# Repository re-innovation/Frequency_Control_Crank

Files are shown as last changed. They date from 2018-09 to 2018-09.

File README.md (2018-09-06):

# Frequency_Control_Crank

A crank handled swicth that controls power to things when turned.
This was built for an update to the Kinetiscopes from Ben Wigley.
Some ifnormation and video is available here:

https://www.re-innovation.co.uk/portfolio/kinetiscopes-a-lost-paradise/

This repository has the arduino nano control code, the design files for the magnetic sensor and datasheets for the control board used.
It also includes some photos.

To Do:

* Upload photos
* Do dimensioned design for future use

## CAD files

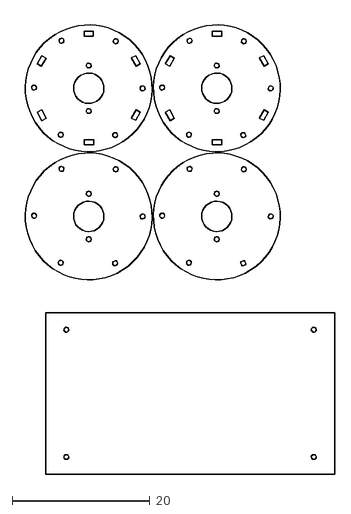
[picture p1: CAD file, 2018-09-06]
Magnet_Holder_Design/magnet holder v1.dxf
46.3 x 66.6

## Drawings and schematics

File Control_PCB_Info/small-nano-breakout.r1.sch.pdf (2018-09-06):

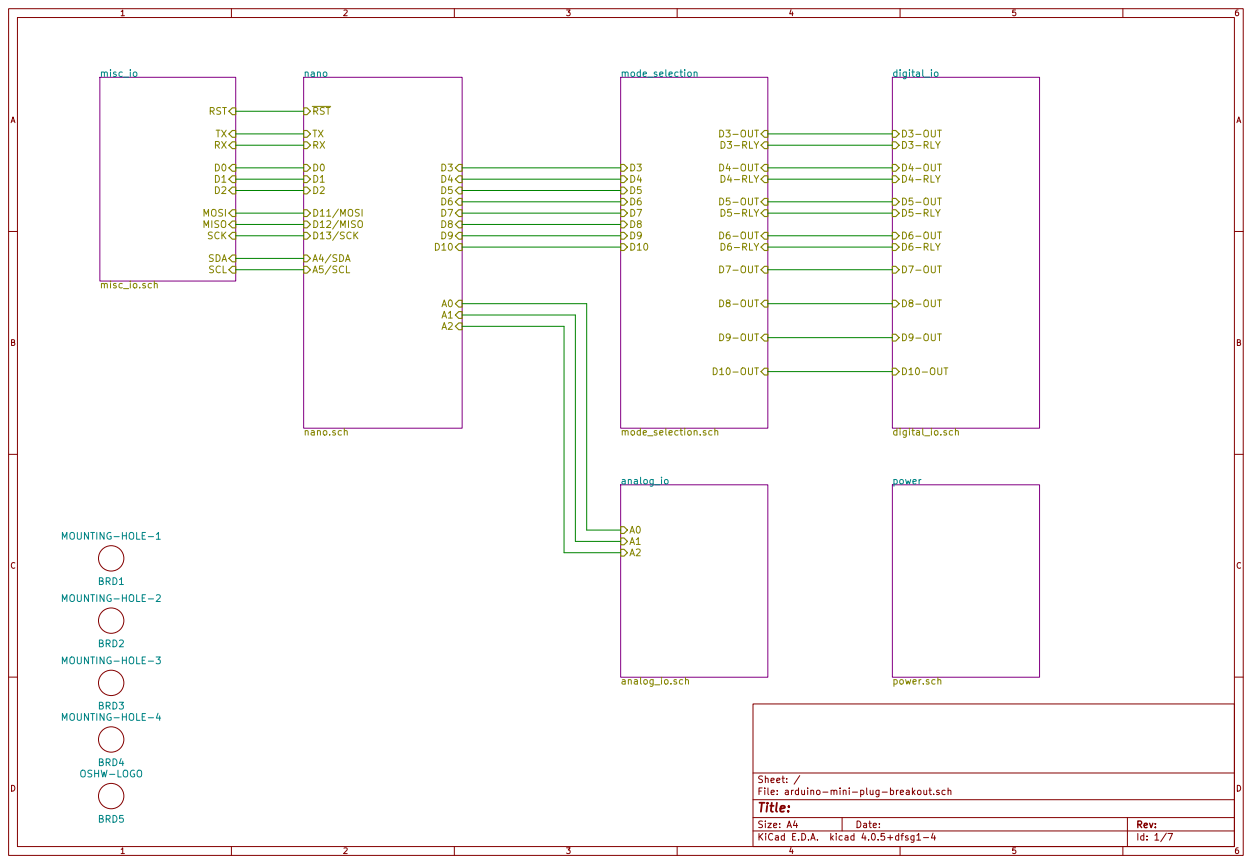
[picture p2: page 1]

D10-OUT D3-RLY D4-RLY D5-RLY D6-RLY mode_selection

BRD4 MOUNTING-HOLE-4 BRD3 MOUNTING-HOLE-3 BRD2 MOUNTING-HOLE-2 BRD1 MOUNTING-HOLE-1

File: arduino-mini-plug-breakout.sch Sheet: /
Id: 1/7 Title:

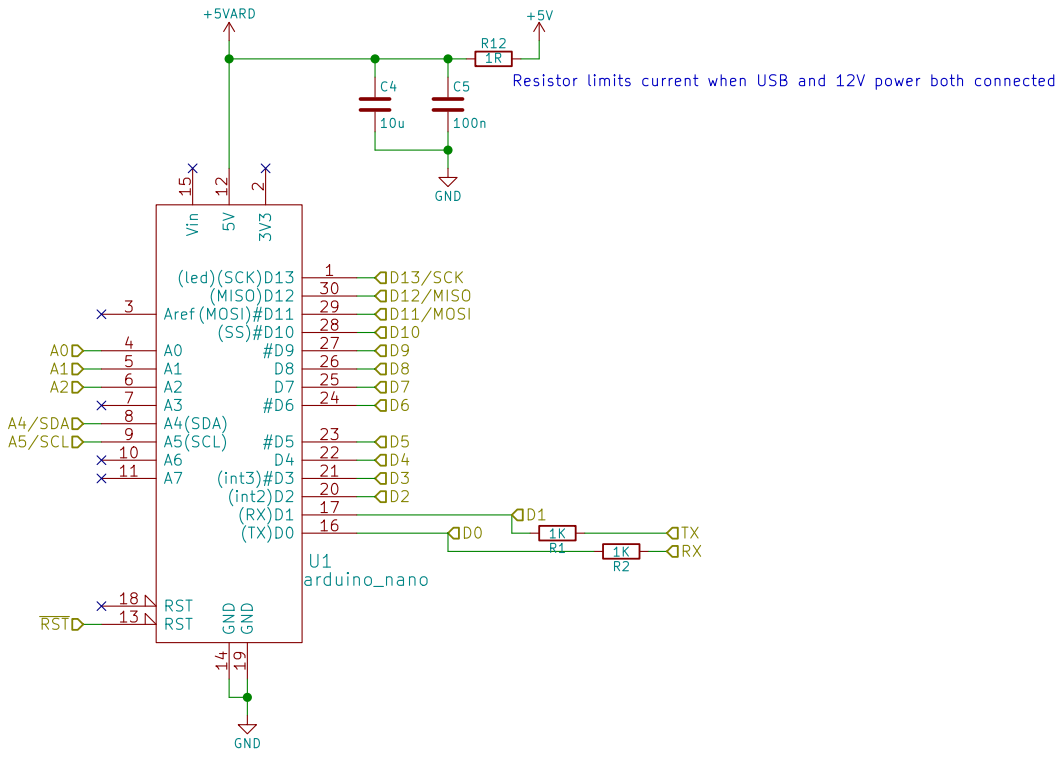
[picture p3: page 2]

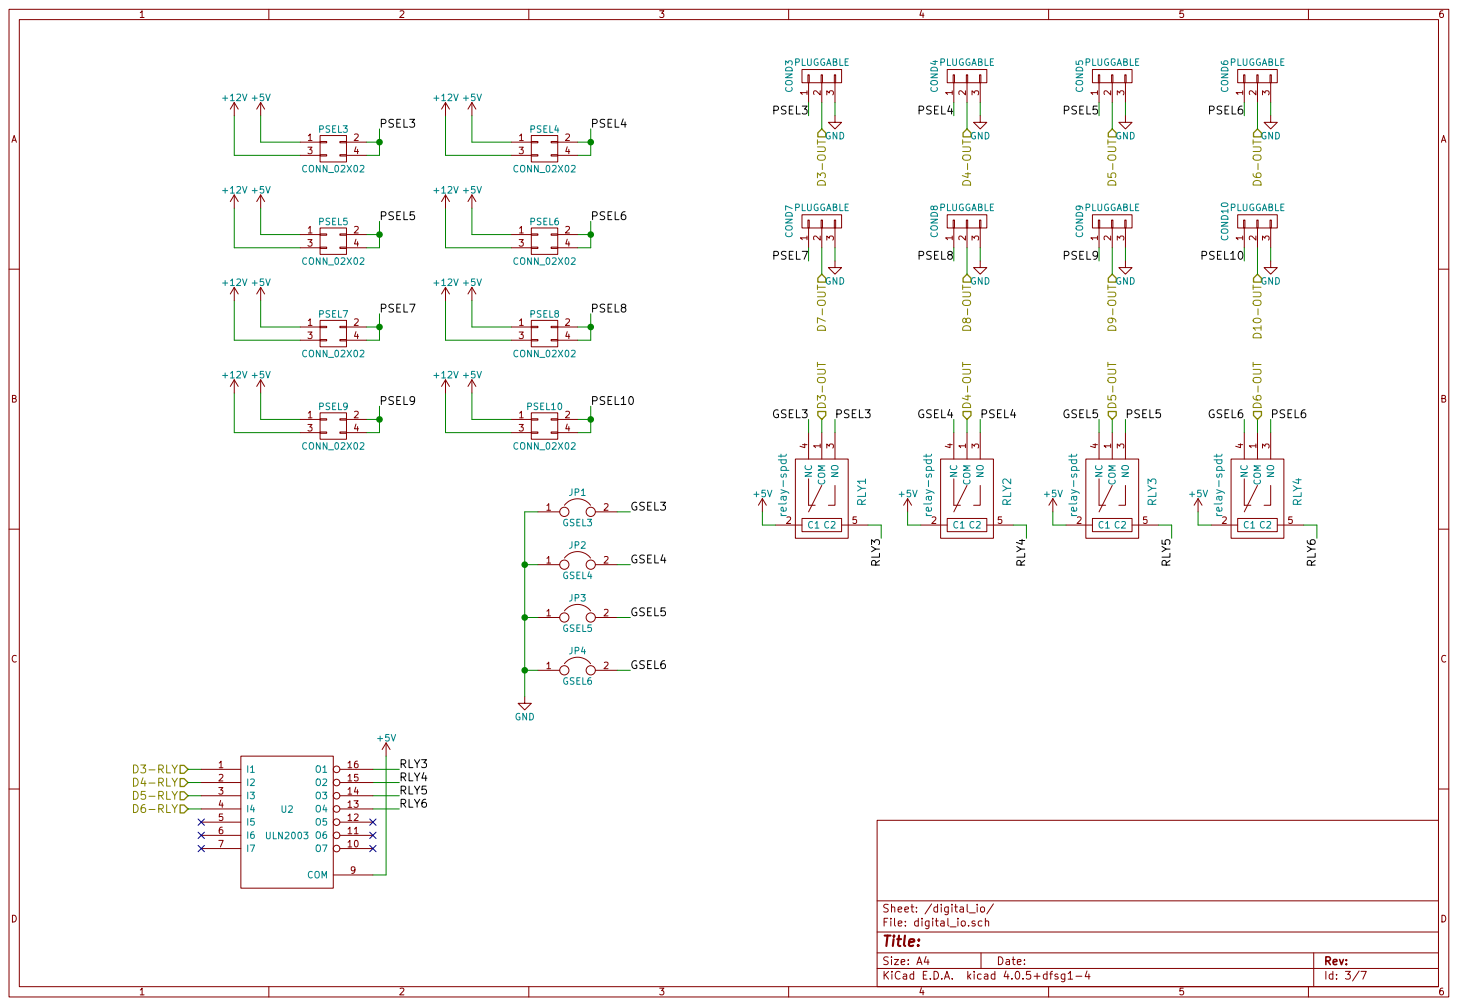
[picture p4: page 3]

3 PLUGGABLE D3-OUT D4-OUT D5-OUT D6-OUT D7-OUT D8-OUT D9-OUT D10-OUT COM

4 C2 5 RLY4 relay-spdt +5V +5V +5V +5V D3-RLY D4-RLY D5-RLY D6-RLY

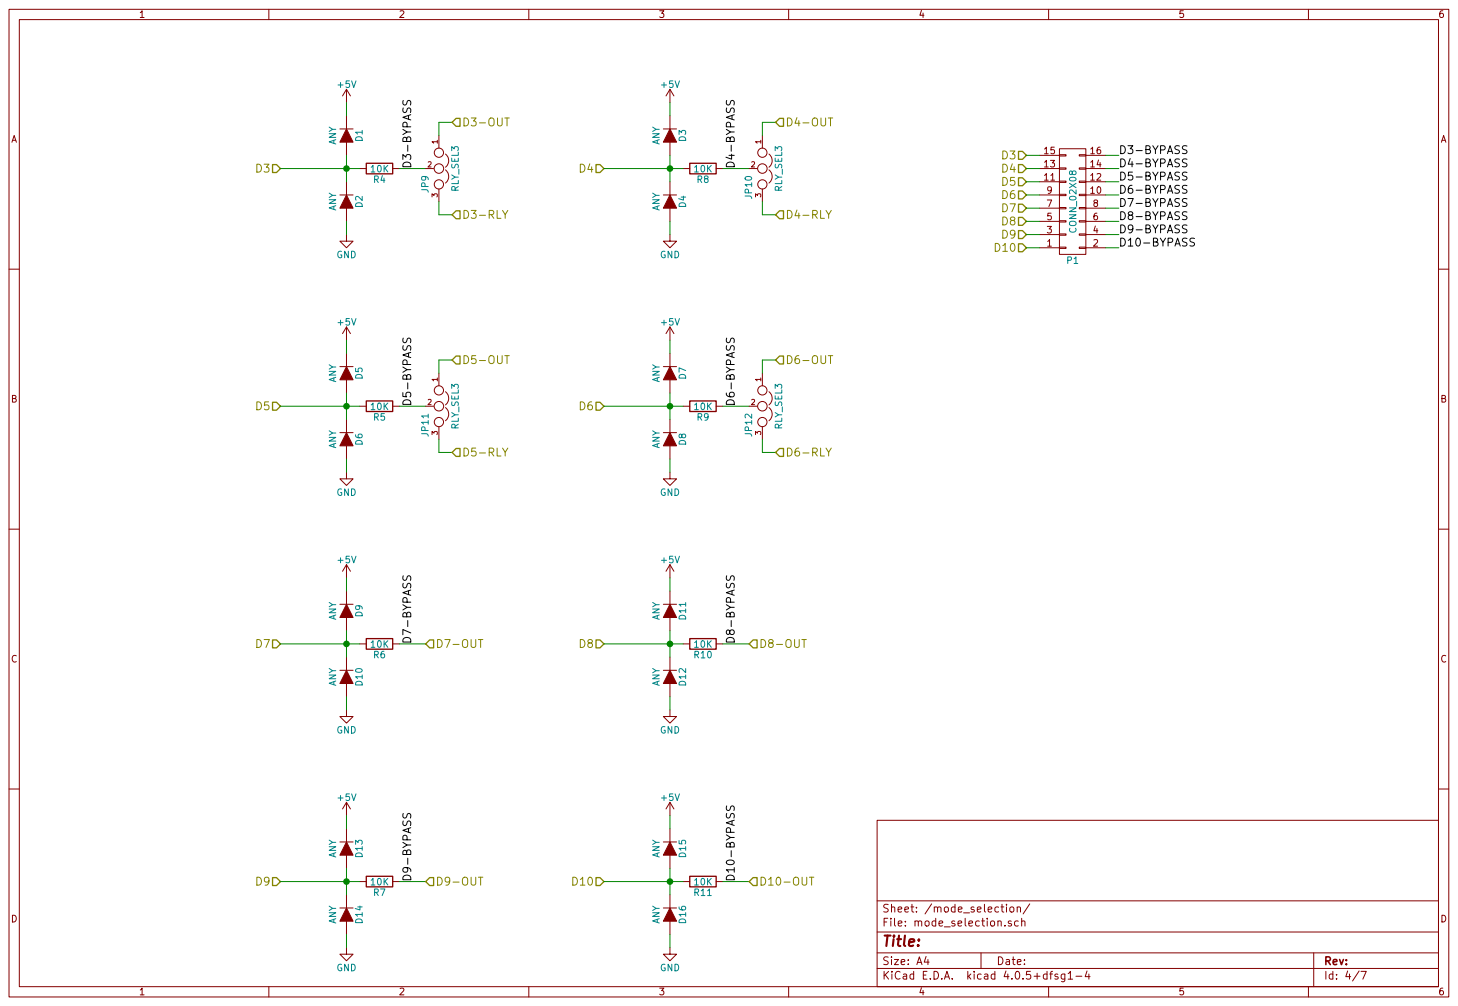
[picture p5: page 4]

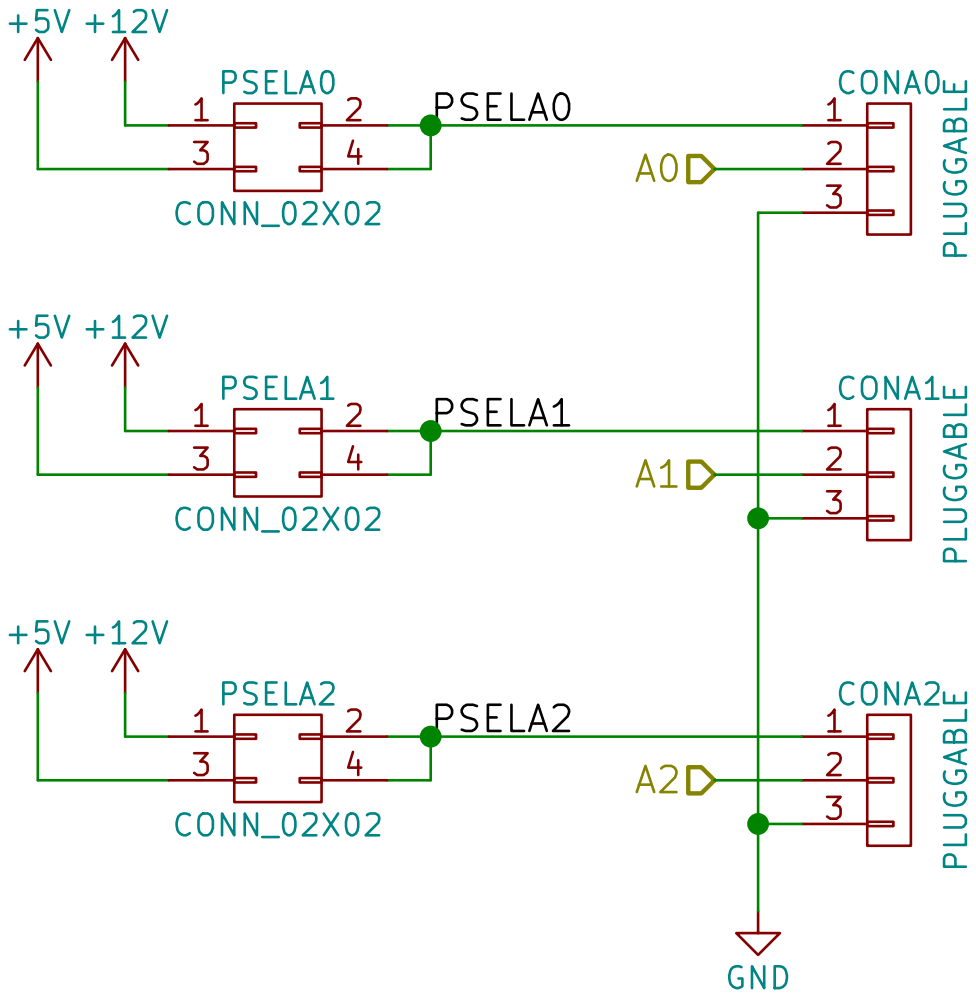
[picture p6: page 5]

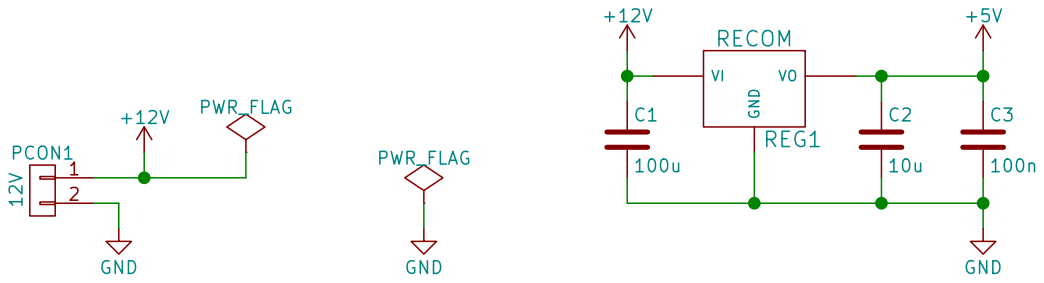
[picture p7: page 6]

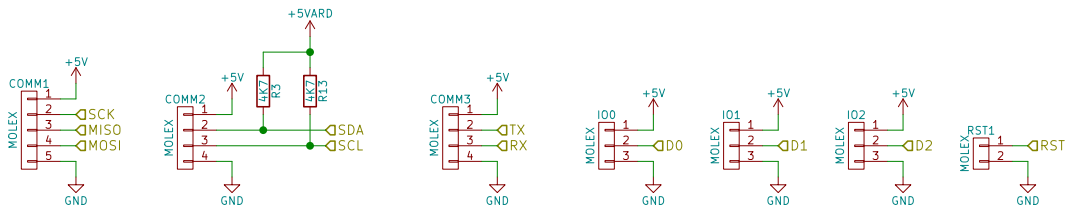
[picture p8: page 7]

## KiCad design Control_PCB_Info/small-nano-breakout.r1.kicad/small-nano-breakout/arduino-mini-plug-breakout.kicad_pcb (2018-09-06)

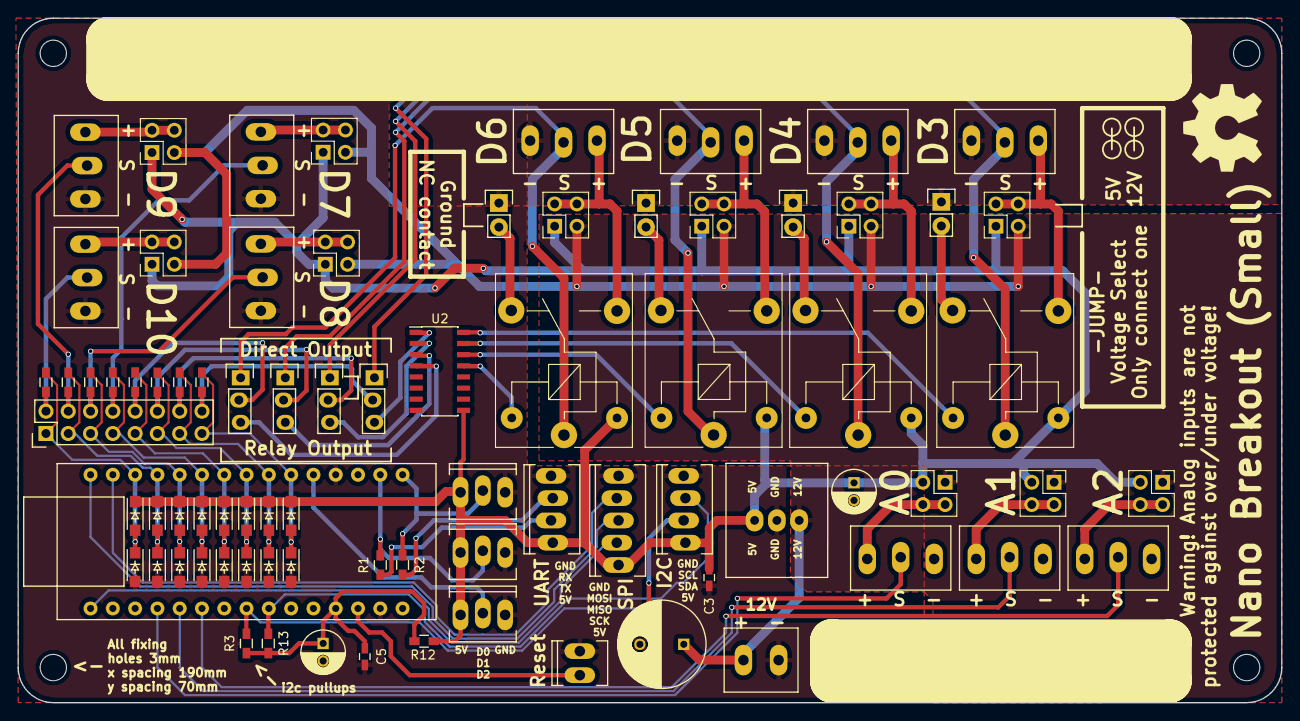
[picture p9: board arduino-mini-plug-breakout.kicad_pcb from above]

Board: 2 copper layers, 144.0 x 78.0 mm, 85 parts (0 on the bottom side), 61 nets.

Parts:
BRD1: MOUNTING-HOLE-1; MountingHole_3mm
BRD2: MOUNTING-HOLE-2; MountingHole_3mm
BRD3: MOUNTING-HOLE-3; MountingHole_3mm
BRD4: MOUNTING-HOLE-4; MountingHole_3mm
BRD5: OSHW-LOGO; OSHW-logo_silkscreen-front_10mm
C1: 100u; C_Radial_D10_L13_P5
C2, C4: 10u; C_Radial_D5_L11_P2
C3, C5: 100n; C_0603_HandSoldering
COMM1: MOLEX; Socket_MOLEX-KK-RM2-54mm_Lock_5pin_straight
COMM2, COMM3: MOLEX; Socket_MOLEX-KK-RM2-54mm_Lock_4pin_straight
CONA0, CONA1, CONA2: PLUGGABLE; Standard_3Way_OffsetHoles
COND3, COND4, COND5, COND6, COND7, COND8, COND9, COND10: PLUGGABLE; Standard_3Way_OffsetHoles
D1, D2, D3, D4, D5, D6, D7, D8, D9, D10, D11, D12, D13, D14, D15, D16: ANY; SOD-123
IO0, IO1, IO2: MOLEX; Socket_MOLEX-KK-RM2-54mm_Lock_3pin_straight
JP1: GSEL3; Pin_Header_Straight_1x02
JP2: GSEL4; Pin_Header_Straight_1x02
JP3: GSEL5; Pin_Header_Straight_1x02
JP4: GSEL6; Pin_Header_Straight_1x02
JP9, JP10, JP11, JP12: RLY_SEL3; Pin_Header_Straight_1x03
P1: CONN_02X08; Pin_Header_Straight_2x08
PCON1: 12V; Standard_2Way_OffsetHoles
PSEL3, PSEL4, PSEL5, PSEL6, PSEL7, PSEL8, PSEL9, PSEL10: CONN_02X02; Pin_Header_Straight_2x02_Pitch2.54mm
PSELA0, PSELA1, PSELA2: CONN_02X02; Pin_Header_Straight_2x02_Pitch2.54mm
R1, R2: 1K; R_0603_HandSoldering
R3, R13: 4K7; R_0603_HandSoldering
R4, R5, R6, R7, R8, R9, R10, R11: 10K; R_0603_HandSoldering
R12: 1R; R_0603_HandSoldering
REG1: RECOM; DCDC-Conv_Recom_R-78HBxx-0.5
RLY1, RLY2, RLY3, RLY4: relay-spdt; Relay_SPDT_SANYOU_SRD_Series_Form_C
RST1: MOLEX; Socket_MOLEX-KK-RM2-54mm_Lock_2pin_straight
U1: arduino_nano; nano
U2: ULN2003; SOIC-16_3.9x9.9mm_Pitch1.27mm

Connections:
+5V: C2.1, C3.1, COMM1.1, COMM2.1, COMM3.1, D1.1, D3.1, D5.1, D7.1, D9.1, D11.1, D13.1, D15.1, IO0.1, IO1.1, IO2.1, PSEL3.1, PSEL4.1, PSEL5.1, PSEL6.1, PSEL7.1, PSEL8.1, PSEL9.1, PSEL10.1, PSELA0.3, PSELA1.3, PSELA2.3, R12.2, REG1.3, RLY1.2, RLY2.2, RLY3.2, RLY4.2, U2.9
+5VARD: C4.1, C5.1, R3.1, R12.1, R13.1, U1.12
+12V: C1.1, PCON1.1, PSEL3.3, PSEL4.3, PSEL5.3, PSEL6.3, PSEL7.3, PSEL8.3, PSEL9.3, PSEL10.3, PSELA0.1, PSELA1.1, PSELA2.1, REG1.1
/analog_io/A0: CONA0.2, U1.4
/analog_io/A1: CONA1.2, U1.5
/analog_io/A2: CONA2.2, U1.6
/analog_io/PSELA0: CONA0.1, PSELA0.2, PSELA0.4
/analog_io/PSELA1: CONA1.1, PSELA1.2, PSELA1.4
/analog_io/PSELA2: CONA2.1, PSELA2.2, PSELA2.4
/digital_io/D3-OUT: COND3.2, JP9.1, RLY1.1
/digital_io/D3-RLY: JP9.3, U2.1
/digital_io/D4-OUT: COND4.2, JP10.1, RLY2.1
/digital_io/D4-RLY: JP10.3, U2.2
/digital_io/D5-OUT: COND5.2, JP11.1, RLY3.1
/digital_io/D5-RLY: JP11.3, U2.3
/digital_io/D6-OUT: COND6.2, JP12.1, RLY4.1
/digital_io/D6-RLY: JP12.3, U2.4
/digital_io/D7-OUT: COND7.2, P1.8, R6.1
/digital_io/D8-OUT: COND8.2, P1.6, R10.1
/digital_io/D9-OUT: COND9.2, P1.4, R7.1
/digital_io/D10-OUT: COND10.2, P1.2, R11.1
/digital_io/GSEL3: JP1.2, RLY1.4
/digital_io/GSEL4: JP2.2, RLY2.4
/digital_io/GSEL5: JP3.2, RLY3.4
/digital_io/GSEL6: JP4.2, RLY4.4
/digital_io/PSEL3: COND3.1, PSEL3.2, PSEL3.4, RLY1.3
/digital_io/PSEL4: COND4.1, PSEL4.2, PSEL4.4, RLY2.3
/digital_io/PSEL5: COND5.1, PSEL5.2, PSEL5.4, RLY3.3
/digital_io/PSEL6: COND6.1, PSEL6.2, PSEL6.4, RLY4.3
/digital_io/PSEL7: COND7.1, PSEL7.2, PSEL7.4
/digital_io/PSEL8: COND8.1, PSEL8.2, PSEL8.4
/digital_io/PSEL9: COND9.1, PSEL9.2, PSEL9.4
/digital_io/PSEL10: COND10.1, PSEL10.2, PSEL10.4
/digital_io/RLY3: RLY1.5, U2.16
/digital_io/RLY4: RLY2.5, U2.15
/digital_io/RLY5: RLY3.5, U2.14
/digital_io/RLY6: RLY4.5, U2.13
/misc_io/D0: IO0.2, R2.2, U1.16
/misc_io/D1: IO1.2, R1.2, U1.17
/misc_io/D2: IO2.2, U1.20
/misc_io/RST: RST1.1, U1.13
/misc_io/RX: COMM3.3, R2.1
/misc_io/TX: COMM3.2, R1.1
/mode_selection/D3: D1.2, D2.1, P1.15, R4.2, U1.21
/mode_selection/D3-BYPASS: JP9.2, P1.16, R4.1
/mode_selection/D4: D3.2, D4.1, P1.13, R8.2, U1.22
/mode_selection/D4-BYPASS: JP10.2, P1.14, R8.1
/mode_selection/D5: D5.2, D6.1, P1.11, R5.2, U1.23
/mode_selection/D5-BYPASS: JP11.2, P1.12, R5.1
/mode_selection/D6: D7.2, D8.1, P1.9, R9.2, U1.24
/mode_selection/D6-BYPASS: JP12.2, P1.10, R9.1
/mode_selection/D7: D9.2, D10.1, P1.7, R6.2, U1.25
/mode_selection/D8: D11.2, D12.1, P1.5, R10.2, U1.26
/mode_selection/D9: D13.2, D14.1, P1.3, R7.2, U1.27
/mode_selection/D10: D15.2, D16.1, P1.1, R11.2, U1.28
/nano/A4/SDA: COMM2.2, R3.2, U1.8
/nano/A5/SCL: COMM2.3, R13.2, U1.9
/nano/D11/MOSI: COMM1.4, U1.29
/nano/D12/MISO: COMM1.3, U1.30
/nano/D13/SCK: COMM1.2, U1.1
GND: C1.2, C2.2, C3.2, C4.2, C5.2, COMM1.5, COMM2.4, COMM3.4, CONA0.3, CONA1.3, CONA2.3, COND3.3, COND4.3, COND5.3, COND6.3, COND7.3, COND8.3, COND9.3, COND10.3, D2.2, D4.2, D6.2, D8.2, D10.2, D12.2, D14.2, D16.2, IO0.3, IO1.3, IO2.3, JP1.1, JP2.1, JP3.1, JP4.1, PCON1.2, REG1.2, RST1.2, U1.14, U1.19, U2.8

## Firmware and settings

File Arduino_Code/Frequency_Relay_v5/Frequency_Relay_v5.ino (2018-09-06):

/*
  This is code for a Frequency Controlled Relay
  This uses NJK-5002C Hall Sensor Proximity Switch NPN 3-wires Normally Open Type
  Wiring: Brown: Power+, Blue:Power-, Black: signal. This needs a 10k pull up resistor on signal wire. 
  Output will go low in presence of a magnet.

  The operation of this unit is:
  Normally - be alseep and low power.
  
  When woken up (with low interrupt on pin D2/INT0)
  Then set relay high
  Check pin D2/INT0 has gone to zero for 5 seconds or more.
  Then set relay low
  Go back to sleep
 
*/

#include <avr/interrupt.h>
#include <avr/power.h>
#include <avr/sleep.h>

#include <avr/io.h>

// pins for the DIO:
const int proximity = 2;   // This is on INT0. This is the magnetic sensor.
const int relay = 3;
const int waitPeriod = 500; // The time to wait (in milliseconds)

int counter = 0;

//int state = LOW;
//int sleepStatus = 0; // variable to store a request for sleep
//unsigned long lastPass = 0;

//int pulseCount = 0; // This holds the pulses from the sensor


void sleepNow()
{

  delay(100);
  // Set switch as interrupt
  // Set pin 2 as interrupt and attach handler:
  attachInterrupt(0, pinInterrupt, FALLING);

  /* Now is the time to set the sleep mode. In the Atmega8 datasheet
     http://www.atmel.com/dyn/resources/prod_documents/doc2486.pdf on page 35
     there is a list of sleep modes which explains which clocks and
     wake up sources are available in which sleep modus.

     In the avr/sleep.h file, the call names of these sleep modus are to be found:

     The 5 different modes are:
     SLEEP_MODE_IDLE -the least power savings
     SLEEP_MODE_ADC
     SLEEP_MODE_PWR_SAVE
     SLEEP_MODE_STANDBY
     SLEEP_MODE_PWR_DOWN -the most power savings

     the power reduction management <avr/power.h> is described in
     http://www.nongnu.org/avr-libc/user-manual/group_avr_power.html
  */

  set_sleep_mode(SLEEP_MODE_PWR_DOWN); // sleep mode is set here

  sleep_enable(); // enables the sleep bit in the mcucr register
  // so sleep is possible. just a safety pin

  power_adc_disable();
  power_spi_disable();
  power_timer0_disable();
  power_timer1_disable();
  power_timer2_disable();
  power_twi_disable();

  sleep_mode(); // here the device is actually put to sleep!!

  // THE PROGRAM CONTINUES FROM HERE AFTER WAKING UP
  sleep_disable(); // first thing after waking from sleep:
  // disable sleep...

  power_all_enable();
}

void pinInterrupt(void)
{
  //detachInterrupt(0);
  counter = waitPeriod; // Reset the counter
  // Does this on interrupt so code can continue

}

void setup() {
  pinMode(relay, OUTPUT);
  pinMode(LED_BUILTIN, OUTPUT);
  pinMode(proximity, INPUT);

  digitalWrite(relay, LOW); // Switch OFF the LEDs?
  digitalWrite(LED_BUILTIN, LOW);

  // initialize serial:
  Serial.begin(9600); // Just for debug, really

  // Add the interrupt
  // This never needs to be detached?
  attachInterrupt(0, pinInterrupt, FALLING);
}

void loop() {

  // Want to stay in this loop.
  // Want to sleep if no serial data
  // *** TO DO ******
  // Go to sleep

  Serial.println("Zzzz...");
  sleepNow();

  // Wake up if proximity sensor goes low
  delay(100);
  Serial.println("Woken Up"); 

  digitalWrite(LED_BUILTIN, HIGH);  // Set the LED/Relay high
  digitalWrite(relay, HIGH);  // Set the LED/Relay high
  
  while(counter>0)
  {
    attachInterrupt(0, pinInterrupt, FALLING);
    counter = counter-1;
    Serial.println(counter);
    delay(10);
  }
  
  attachInterrupt(0, pinInterrupt, FALLING);
  
  digitalWrite(LED_BUILTIN, LOW);  // Set the LED/Relay low
  digitalWrite(relay, LOW);  // Set the LED/Relay high
    
  delay(100);

}
